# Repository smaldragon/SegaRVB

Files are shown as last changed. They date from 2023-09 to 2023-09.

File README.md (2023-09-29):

# Sega R.V.B. Clone Board

This is a clone of the "Adapteur R.V.B.", used by the french market Master System II for video output, based on the schematics avaliable at [SMSPower.org](https://www.smspower.org/Development/AdapteurRVB).

This board is intended to be a cheap diy option for consoles which have lost their original cable, and comes with all the quirks of the original circuit.

The wires of a custom DIN-8 AV cable should be soldered to the through hole pins in the bottom of the board to connect the board to an original console.

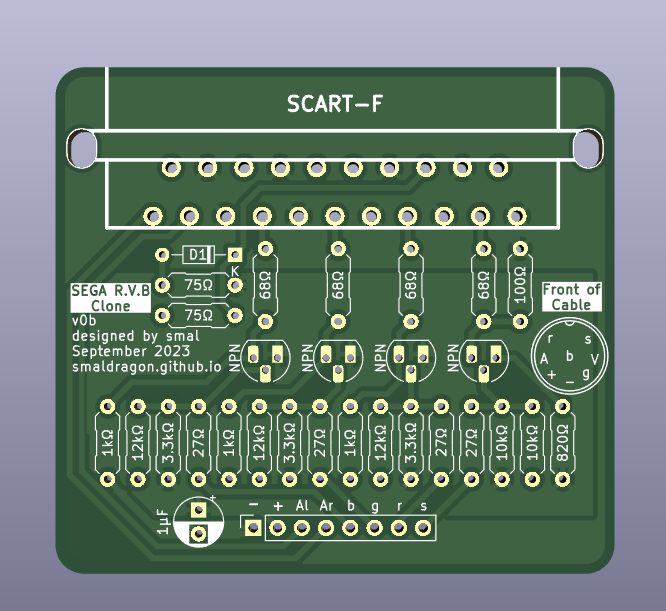
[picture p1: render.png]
circuit board render

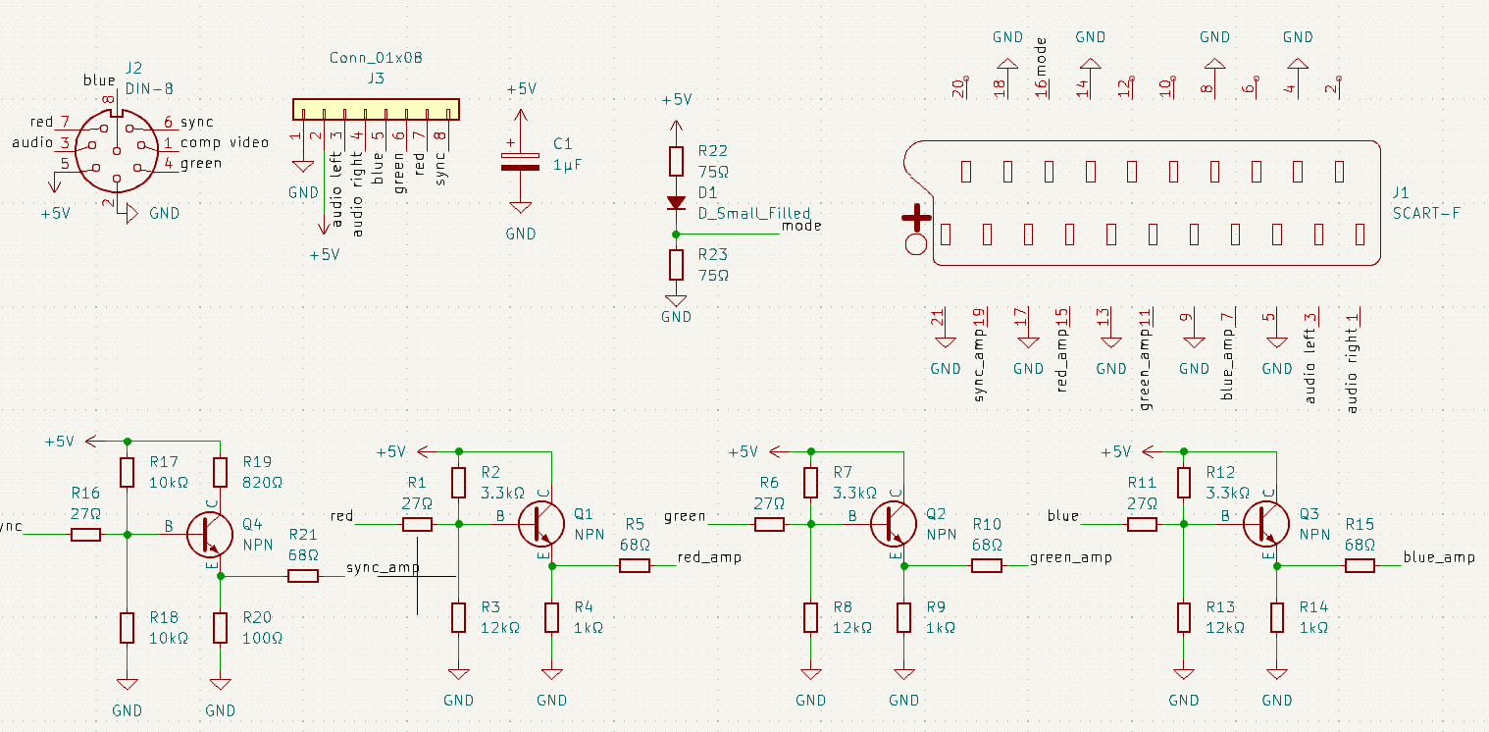
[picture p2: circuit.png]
circuit schematic


> Note: the non-critical 12V pin 8 signal which sets the tv to 4:3 mode has been ommitted from this board for simplification.

## Bill of Materials

The location and values of all Components are specified on the board itself.

| Component | Quantity |
|---|---|
| Female PCB SCART Connector | 1 |
| 1µF Decoupling Capacitor | 1 |
| Generic Diode | 1 |
| Generic NPN Transistor | 4 |
| 27Ω Resistor | 4 |
| 68Ω Resistor | 4 |
| 75Ω Resistor | 2 |
| 100Ω Resistor | 1 |
| 820Ω Resistor | 1 |
| 1kΩ Resistor | 3 |
| 3.3kΩ Resistor | 3 |
| 10kΩ Resistor | 2 |
| 12kΩ Resistor | 3 |

## Files

The `kicad` folder contains the original files used to produce the board
The `gerber` folder contain zip files with the gerber files for board production

## Revisions

As of 2023-09-29, my latest board revision is **v0b**

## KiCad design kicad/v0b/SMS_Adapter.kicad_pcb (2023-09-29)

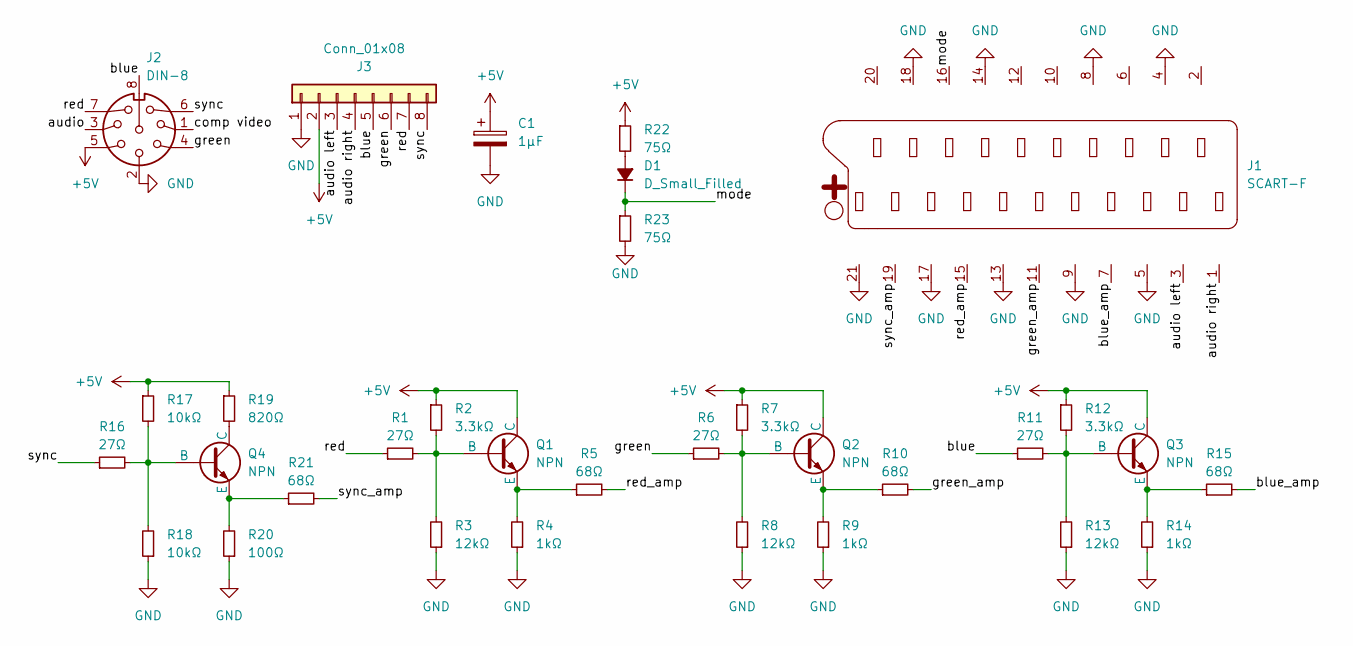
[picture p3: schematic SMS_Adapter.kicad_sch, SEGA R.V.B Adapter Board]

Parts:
C1: 1µF; CP_Radial_D5.0mm_P2.50mm
D1: D_Small_Filled; D_DO-34_SOD68_P7.62mm_Horizontal
J1: SCART-F; SCART
J2: DIN-8
J3: Conn_01x08; PinSocket_1x08_P2.54mm_Vertical
Q1, Q2, Q3, Q4: NPN; TO-92L_HandSolder
R1, R6, R11, R16: 27Ω; R_Axial_DIN0207_L6.3mm_D2.5mm_P7.62mm_Horizontal
R2, R7, R12: 3.3kΩ; R_Axial_DIN0207_L6.3mm_D2.5mm_P7.62mm_Horizontal
R3, R8, R13: 12kΩ; R_Axial_DIN0207_L6.3mm_D2.5mm_P7.62mm_Horizontal
R4, R9, R14: 1kΩ; R_Axial_DIN0207_L6.3mm_D2.5mm_P7.62mm_Horizontal
R5, R10, R15, R21: 68Ω; R_Axial_DIN0207_L6.3mm_D2.5mm_P7.62mm_Horizontal
R17, R18: 10kΩ; R_Axial_DIN0207_L6.3mm_D2.5mm_P7.62mm_Horizontal
R19: 820Ω; R_Axial_DIN0207_L6.3mm_D2.5mm_P7.62mm_Horizontal
R20: 100Ω; R_Axial_DIN0207_L6.3mm_D2.5mm_P7.62mm_Horizontal
R22, R23: 75Ω; R_Axial_DIN0207_L6.3mm_D2.5mm_P7.62mm_Horizontal

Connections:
+5V: C1.1, J2.5, J3.2, Q1.1 (C), Q2.1 (C), Q3.1 (C), R2.1, R7.1, R12.1, R17.1, R19.1, R22.1
/audio left: J1.3, J3.3
/audio right: J1.1, J3.4
/blue: J2.8, J3.5, R11.1
/blue_amp: J1.7, R15.2
/green: J2.4, J3.6, R6.1
/green_amp: J1.11, R10.2
/mode: D1.1 (K), J1.16, R23.1
/red: J2.7, J3.7, R1.1
/red_amp: J1.15, R5.2
/sync: J2.6, J3.8, R16.1
/sync_amp: J1.19, R21.2
GND: C1.2, J1.4, J1.5, J1.8, J1.9, J1.13, J1.14, J1.17, J1.18, J1.21, J2.2, J3.1, R3.1, R4.1, R8.1, R9.1, R13.1, R14.1, R18.1, R20.1, R23.2
unnamed: D1.2 (A), R22.2
unnamed: Q1.2 (B), R1.2, R2.2, R3.2
unnamed: Q1.3 (E), R4.2, R5.1
unnamed: Q2.2 (B), R6.2, R7.2, R8.2
unnamed: Q2.3 (E), R9.2, R10.1
unnamed: Q3.2 (B), R11.2, R12.2, R13.2
unnamed: Q3.3 (E), R14.2, R15.1
unnamed: Q4.2 (B), R16.2, R17.2, R18.2
unnamed: Q4.1 (C), R19.2
unnamed: Q4.3 (E), R20.2, R21.1

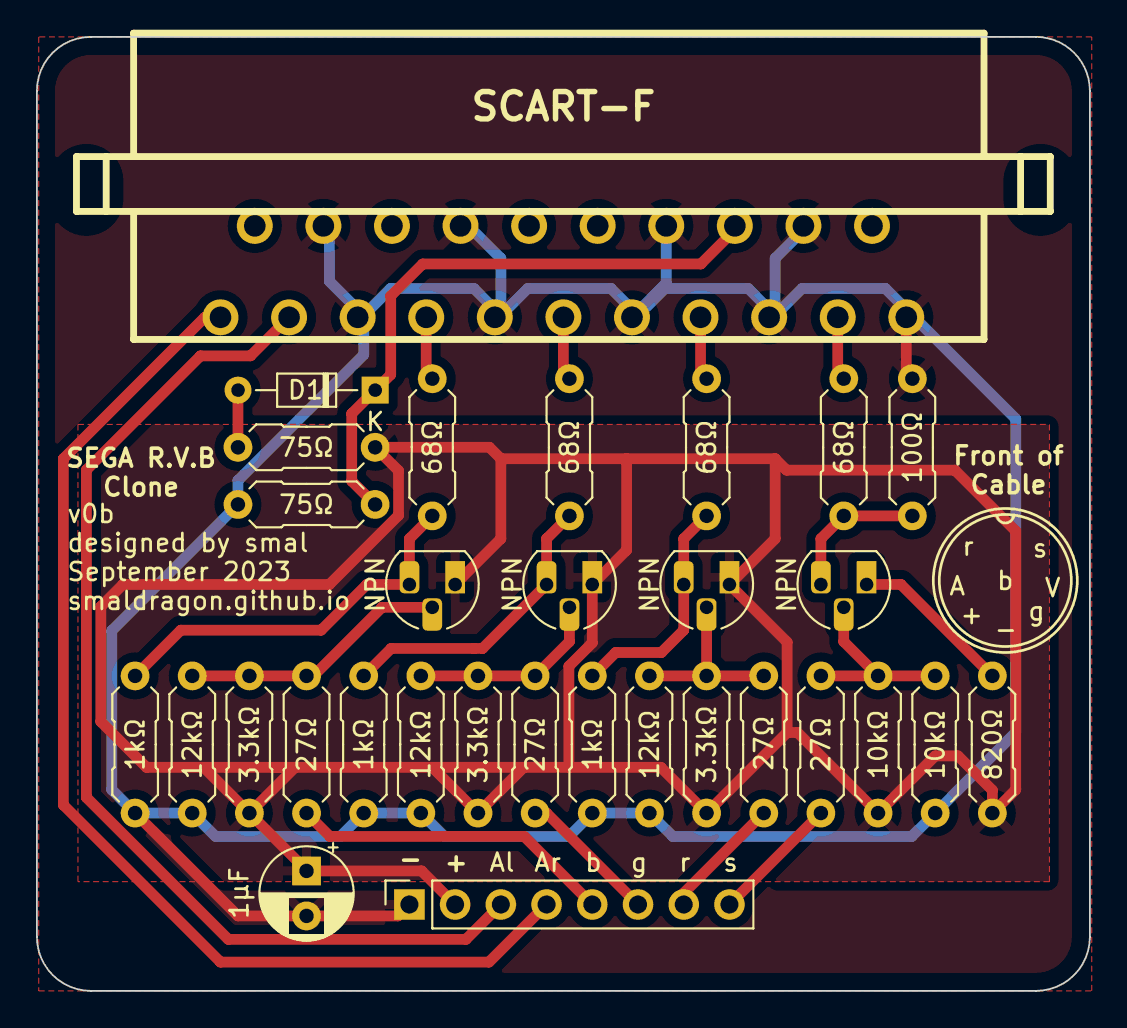
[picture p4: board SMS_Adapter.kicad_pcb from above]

Board: 2 copper layers, 58.5 x 53.0 mm, 31 parts (0 on the bottom side), 23 nets.

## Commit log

2023-09-29 Initial file commit
    [SMS_Adapter.kicad_pcb, SMS_Adapter.kicad_sch]
2023-09-29 add circuit schematic image
